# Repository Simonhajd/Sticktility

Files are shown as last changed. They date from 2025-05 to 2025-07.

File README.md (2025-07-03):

Stick-Tility (Stick Utility)

## About the Project / What it is:

Stick-Tility is a  handheld device that powers and reads data from snap-on sensor modules. Once a sensor is connected, it can record data at set time intervals and graph the data on its screen. It can charge via the USB-C on the side, and the KB2040 Microcontroller can be updated or connected to a computer using the same USB-C port. This all fits in a durable case smaller than a TV remote.

### Use cases:
* UV exposure logger
* * For example, you could easily set it up to record and display the current UV level and notify you when it reaches a certain threshold. Then you could just swap the UV sensor with a VOC sensor and it would instantly show you data about your air quality.
* Gps recorder for activities
* Analyzing trends in weather
* VOC warning system
* Distance measuring tool
* Noise level safety warning
  
## My process:
When I was thinking of a project to create for Highway, I started by constraining myself to one of these four categories: Tools, Displays, Devices, and Interfaces. I chose to make a tool because I wanted something I could actually use. I decided on making the most compact tool I could. I came up with a few more contraints (handheld, battery powered), and started developing the tool. 

### Why:

I want to be able to use sensors more easily without wiring or breadboards. Stick-Tility removes the bulky computer and battery aspect of each individual tool and sensor, so you can simply snap on the sensor (with pogo pins, like a MacBook charger), and you will receive data. This means, for each sensor you would like to use, you just need the sensor (with i2c), and you just plug it in using a pogo system. One battery for everything. I wanted to build this since I loved the concept of a hot-swappable sensor device for whatever you'd like, that fits in your hand, with a hot-swappable sensor end which snaps on using just magnets and pins. 

Screenshot 2025-07-03 at 8 59 43 AM

Screenshot 2025-06-21 at 3 33 17 PM

Screenshot 2025-06-21 at 3 33 07 PM

## Case design process:

I designed the case to be easily taken apart for debugging/removal while still sitting solidly together. I came up with the concept of two "skeleton" parts I can slide over the PCB and battery to keep them in place, and a shell which I can slide the electronics into. after many tens of hours of work on the case, I came up with a design that should be very robust, as small as possible, and easy to use. I also have magnets to attach the additional components, and to snap the skeletons into the shell.

Screenshot 2025-06-21 at 3 21 40 PM

I created an explosion video of the model too to visualize the parts required on the build:

https://github.com/user-attachments/assets/41e0f8f3-01ee-4bec-a7f7-713455e94a45

### Past projects: 
The only PCB work I’ve done before is a single-layer PCB macropad. https://github.com/Simonhajd/Macropad. Ive done some cad practice but no projects. This was mostly the first time ive really challenged myself with CAD. Other than these, I have only done software/online work.

### Why this is worth 10 points: 
This isnt just a data reading device, this is a dynamic tool which can be easily programmed to compile data and visualize it, or record data over time. the device is allowed to be placed anywhere, start a recording, and log data every x hours. This product has the ability to be a part of a much larger ecosystem of tools and sensors. The intricate build of this case allows anything to be modularly swapped, and nothing is glued. There are so many parts which fit so seamlessly together to become one rigid device. Just two screws are used, and everything is held together by other objects, or magnets. The PCB contains two off-the-shelf boards, and many other features to optimize reliability and quality. Such as decoupling capacitors, data line tuning, and much more. And finally, roughly 67 hours were spent on this project.

### Total Hours spent: 66 Hours 33 Minutes

### Total price: $158.44

## BOM:

| Qty | Part | P/N | Supplier | Price | Link | Shipping + Tariffs | Tax | Total |
|-----|---|-----|---|---|---|---|-----|---|
| 1 | Adafruit PowerBoost 1000 Charger - Rechargeable 5V Lipo USB Boost @ 1A - 1000C | N/A | Adafruit | 19.95 | [Link](https://www.adafruit.com/product/2465) | 1.72 | 2.167 | 23.837 |
| 1 | On-Off Power Button / Pushbutton Toggle Switch | 1683 | Adafruit | 1.95 | [Link](https://www.adafruit.com/product/1683?gQT=1) | 1.92 | 0.387 | 4.257 |
| 1 | Adafruit KB2040 | 5302 | Adafruit | 8.95 | [Link](https://www.adafruit.com/product/5302) | 1.92 | 1.087 | 0 (own) |
| 1 | 2A Waterproof Magnetic Pogo Pin Connector (Male/Female) | N/A | Aliexpress | 13.38 | [Link](https://www.aliexpress.us/item/3256808648425959.html) | 0 | 1.338 | 14.718 |
| 1 | Gravity: GNSS GPS BeiDou Positioning Module with RTC - I2C&UART | DFR1103 | DFRobot | 17.9 | [Link](https://www.dfrobot.com/product-2815.html) | 15 | 3.29 | 36.19 |
| 1 | 128x64 OLED - SSD1306 - I2C | WEA012864DWPP3N00003 | Digikey | 9.53 | [Link](https://www.digikey.com/en/products/detail/winstar-display/WEA012864DWPP3N00003/20533255) | 1.208 | 1.0738 | 11.8118 |
| 1 | Decoupling Capacitor | C0402C104K9RACTU | Digikey | 0.1 | [Link](https://www.digikey.com/en/products/detail/kemet/c0402c104k9ractu/1090777) | 1.208 | 0.1308 | 1.4388 |
| 2 | 5.1kΩ Resistors | RC0603FR-075K1L | Digikey | 0.1 | [Link](https://www.digikey.com/en/products/detail/yageo/RC0603FR-075K1L/727268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) | 1.208 | 0.1308 | 1.4388 |
| 11 | 1mΩ Resistors | TLR3AWDTE2L00F | Digikey | 1.53 | [Link](https://www.digikey.com/en/products/detail/koa-speer-electronics-inc/tlr3awdte2l00f/9845546) | 1.208 | 0.2738 | 3.0118 |
| 1 | USB-C Connector | UJ31-CH-G-SMT-TR-67 | Digikey | 3.52 | [Link](https://www.digikey.com/en/products/detail/same-sky-formerly-cui-devices/UJ31-CH-G-SMT-TR-67/12702600) | 1.208 | 0.4728 | 5.2008 |
| 100 | Screw x2 | 90128A187 | McMaster-Carr | 8.41 | [Link](https://www.mcmaster.com/catalog/131/3561/90128A187) | 3.61 | 1.202 | 0 (own) |
| 1 | 2.40mm M3 Hex Nut x2 | 90591A250 | McMaster-Carr | 2.81 | [Link](https://www.mcmaster.com/catalog/131/3648/90591A250) | 3.61 | 0.642 | 0 (own) |
| 8 | Magnets (Disc OD 0.197) | 5902K47 | McMaster-Carr | 1.09 | [Link](https://www.mcmaster.com/products/magnets/magnets-2~/shape~disc/od~0-197/) | 3.61 | 0.47 | 5.17 |
| 1 | Adafruit Lithium Ion Cylindrical Battery - 3.7V 2200mAh | 1781 | Adafruit | 9.95 | [Link](https://www.adafruit.com/product/1781) | 1.92 | 1.187 | 13.057 |
| 1 | Sparkfun Multi-Directional Switch 5 Position - D-Pad (SMD) | COM-26850 | Sparkfun | 0.95 | [Link](https://www.sparkfun.com/multi-directional-switch-5-position-d-pad-smd.html) | 2.825 | 0.3775 | 4.1525 |
| 1 | Flexible Qwiic Cable - 200mm | PRT-17258 | Sparkfun | 1.95 | [Link](https://www.sparkfun.com/flexible-qwiic-cable-200mm.html) | 2.825 | 0.4775 | 5.2525 |
| 1 | Qwiic Cable - 100mm (cut in half) | PRT-14427 | Sparkfun | 1.5 | [Link](https://www.sparkfun.com/qwiic-cable-100mm.html) | 2.825 | 0.4325 | 4.7575 |
| 1 | SparkFun Micro Temperature Sensor | STTS22H | Sparkfun | 8.53 | [Link](https://www.sparkfun.com/sparkfun-micro-temperature-sensor-stts22h-qwiic.html) | 2.825 | 1.1355 | 12.4905 |
| 1 | PCB | N/A | JLCPCB | 2.1 | PCB in repo | 8.5 | 1.06 | 11.66 |

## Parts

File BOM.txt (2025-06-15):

UJ31-CH-G-SMT-TR-67 USB-C

2x 5.1kΩ resistors  - RC0603FR-075K1L

2x 1mohm resistors

Adafruit PowerBoost 1000 Charger - Rechargeable 5V Lipo USB Boost @ 1A - 1000C

Sparkfun Lithium Ion Cylindrical Battery - 3.7v 2200mAh

Sparkfun Multi-Directional Switch 5 Position - D-Pad (SMD)

On-Off Power Button / Pushbutton Toggle Switch - Aadafruit Product ID: 1683

https://www.aliexpress.us/item/3256808648425959.html

adafruit kb2040

128x64 OLED - SSD1306 - I2C

SparkFun Qwiic Connect System - 10cm Jumper Wires

decoupling cap: C0402C104K9RACTU X 4

Weather - 

SparkFun Micro Temperature Sensor - STTS22H (Qwiic)

GNSS - 

MAX-F10S L1/L5 dual-band GNSS receiver for sub meter-level accuracy with SMA connector

u-blox Multi-band Active GNSS Antenna - L1, L5 (ANN-MB5)

SCREWS

NUTS

UPDATE CAPACITOR ON MAIN BUILD TO BE THE CORRECT PAD SPACING. I DID NOT CHECK THIS 

CHECK THAT THE PIN NUMBERS CORRELATE TO THE CORRECT PADS. DID NOT CHECK THIS

X2 95263A134_Alloy Steel Socket Head Screw 

2X 2.40mm mM3 Hex Nut

MAGNETS * 8 5.75x2mm

NOT USING: 

"Node" system:

BA1AAPC battery holder

RP2040
RFM95CW radio module
PCB.SMAFRA.HT jack
TLV73333PDBVR regulator
CC0402KRX5R5BB105 1uF decoupling capacitor
ANT-915-NUB-ccc 915 MHz LPWA Whip Antenna

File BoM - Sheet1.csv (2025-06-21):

Quantity | Part | P/N | Supplier | Price | Link | Shipping + Tariffs | Tax | Total
1 | Adafruit PowerBoost 1000 Charger - Rechargeable 5V Lipo USB Boost @ 1A - 1000C | N/A | Adafruit | 19.95 | https://www.adafruit.com/product/2465 | 1.72 | 2.167 | 23.837
1 | On-Off Power Button / Pushbutton Toggle Switch - Aadafruit Product ID: 1683 | 1683 | Adafruit | 1.95 | https://www.adafruit.com/product/1683?gQT=1 | 1.92 | 0.387 | 4.257
1 | adafruit kb2040 | 5302 | Adafruit | 8.95 | https://www.adafruit.com/product/5302 | 1.92 | 1.087 | 11.957
1 | 1/5Pair 2A Waterproof Magnetic Pogo Pin Connector 2 3 4 5 6 Positions Pogopin Male Female 2.54 MM Spring Loaded DC Power Socket |  | Aliexpress | 13.38 | https://www.aliexpress.us/item/3256808648425959.html | 0 | 1.338 | 14.718
1 | Gravity: GNSS GPS BeiDou Positioning Module with RTC - I2C&UART | DFR1103 | DFRobot | 25.9 | https://www.dfrobot.com/product-2815.html | 15 | 4.09 | 44.99
1 | 128x64 OLED - SSD1306 - I2C | 3190-DLC0096DNOG-W-10-ND | Digikey | 33.41 | https://www.digikey.com/en/products/detail/dlc-display-co-ltd/DLC0096DNOG-W-10/24764440 | 1.208 | 3.4618 | 38.0798
1 | Decoupling Capacitor | C0402C104K9RACTU | Digikey | 0.1 | https://www.digikey.com/en/products/detail/kemet/c0402c104k9ractu/1090777 | 1.208 | 0.1308 | 1.4388
2 | 5.1kΩ resistors | RC0603FR-075K1L | Digikey | 0.1 | https://www.digikey.com/en/products/detail/yageo/RC0603FR-075K1L/727268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 | 1.208 | 0.1308 | 1.4388
11 (same price) | 1mohm resistors | TLR3AWDTE2L00F | Digikey | 1.53 | https://www.digikey.com/en/products/detail/koa-speer-electronics-inc/tlr3awdte2l00f/9845546 | 1.208 | 0.2738 | 3.0118
1 | USB-C | UJ31-CH-G-SMT-TR-67 | Digikey | 3.52 | https://www.digikey.com/en/products/detail/same-sky-formerly-cui-devices/UJ31-CH-G-SMT-TR-67/12702600 | 1.208 | 0.4728 | 5.2008
100 | Screw - x 2 | 90128A187 | McMaster-Carr | 8.41 | https://www.mcmaster.com/catalog/131/3561/90128A187 | 3.61 | 1.202 | 13.222
1 | 2.40mm M3 Hex Nut x 2 | 90591A250 | McMaster-Carr | 2.81 | https://www.mcmaster.com/catalog/131/3648/90591A250 | 3.61 | 0.642 | 7.062
8 | MAGNETS - | 5902K47 | McMaster-Carr | 1.09 | https://www.mcmaster.com/products/magnets/magnets-2~/shape~disc/od~0-197/ | 3.61 | 0.47 | 5.17
1 | Adafruit Lithium Ion Cylindrical Battery - 3.7v 2200mAh | 1781 | Adafruit | 9.95 | https://www.adafruit.com/product/1781 | 1.92 | 1.187 | 13.057
1 | Sparkfun Multi-Directional Switch 5 Position - D-Pad (SMD) | COM-26850 | Sparkfun | 0.95 | https://www.sparkfun.com/multi-directional-switch-5-position-d-pad-smd.html | 2.825 | 0.3775 | 4.1525
1 | Flexible Qwiic Cable - 200mm | PRT-17258 | Sparkfun | 1.95 | https://www.sparkfun.com/flexible-qwiic-cable-200mm.html | 2.825 | 0.4775 | 5.2525
1 | Qwiic Cable - 100mm (going to cut in half) | PRT-14427 | Sparkfun | 1.5 | https://www.sparkfun.com/qwiic-cable-100mm.html | 2.825 | 0.4325 | 4.7575
1 | SparkFun Micro Temperature Sensor | STTS22H | Sparkfun | 8.53 | https://www.sparkfun.com/sparkfun-micro-temperature-sensor-stts22h-qwiic.html | 2.825 | 1.1355 | 12.4905
1 | PCB |  | JLCPCB | 2.1 | PCB in repo | 8.5 | 1.06 | 11.66
 |  |  |  |  |  |  | Total Price | 225.753

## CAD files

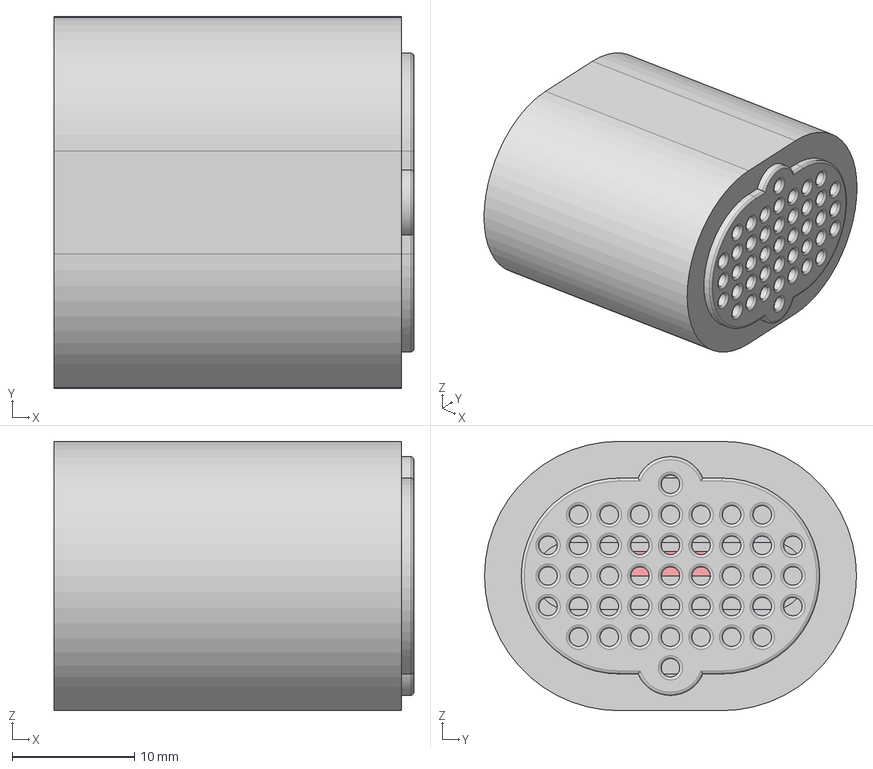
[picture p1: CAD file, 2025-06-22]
3D Models/Weathermodule.step
29.4 x 30.4 x 22.0 mm
Weathercase
WeatherSensor
WeatherMag
WeatherMag (1)

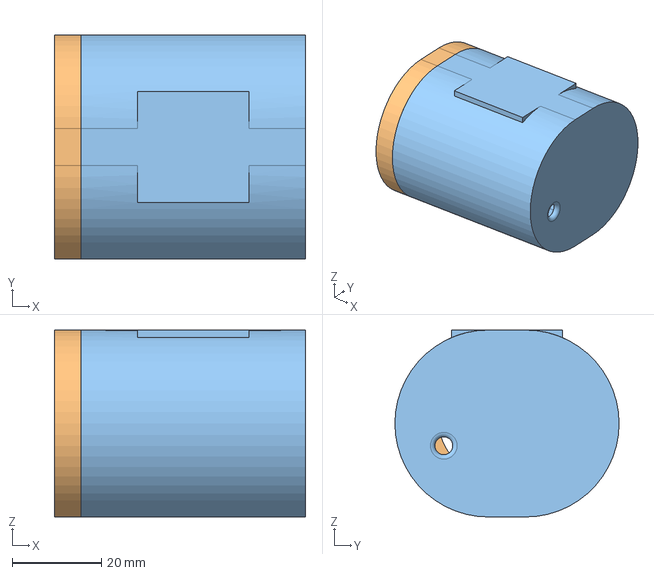
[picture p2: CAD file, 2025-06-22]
3D Models/GNSSBuild.step
56.4 x 50.4 x 42.0 mm

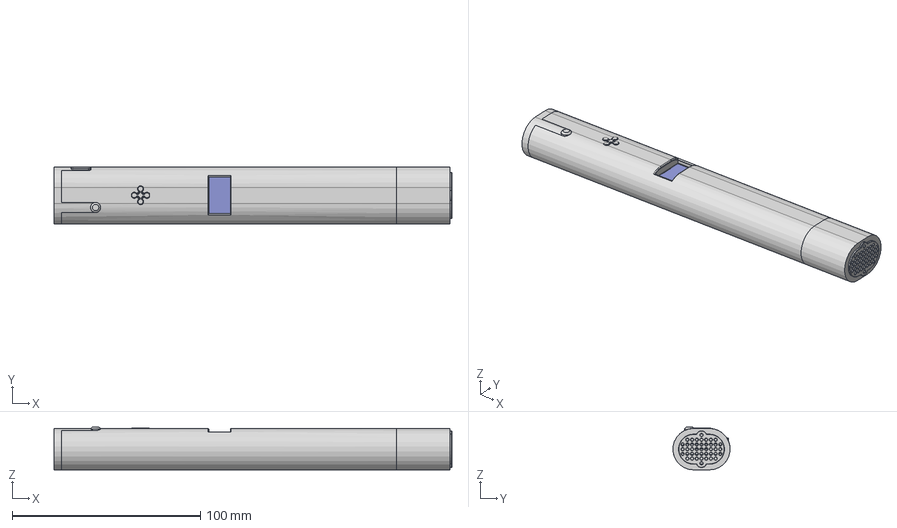
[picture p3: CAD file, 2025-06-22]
3D Models/Case v33.step
211.2 x 30.3 x 22.7 mm
Configuration 1
C_0201_0603Metric x 4
Navigation_SMD_9.9x9.9mm
R_0603_1608Metric x 4
board
screen
pin_header
soldering
smd_capacitor
smd_capacitor (1)
914_smd_resistor
472_smd_resistor x 3
t4_smd_diode
smd_capacitor (2)
smd_capacitor (3)
smd_capacitor (4)
smd_capacitor (5)
smd_capacitor (6)
472_smd_resistor (1)
SOT-23_XC6206 v3
smd_capacitor (7)
flat_cable
UJ31-CH-G-SMT-TR-67
powerboost 1000c.f3d v3_1
molex_0473460001
skibidishort 1.12.1
mightbeshit_PCB
90592A085_Steel Hex Nut x 2
90128A187_Zinc-Plated Alloy Steel Socket Head Screw x 2
Weatherbox
WeatherSensor
WeatherMag (1)
WeatherMag
Weathercase
Cap
SmallSupportPins
BottomCage
BigSupportPins (1)
SmallSupportPins (1)
ShellMagnets
Button
TopCage
Outside
ShellMagnets (1)

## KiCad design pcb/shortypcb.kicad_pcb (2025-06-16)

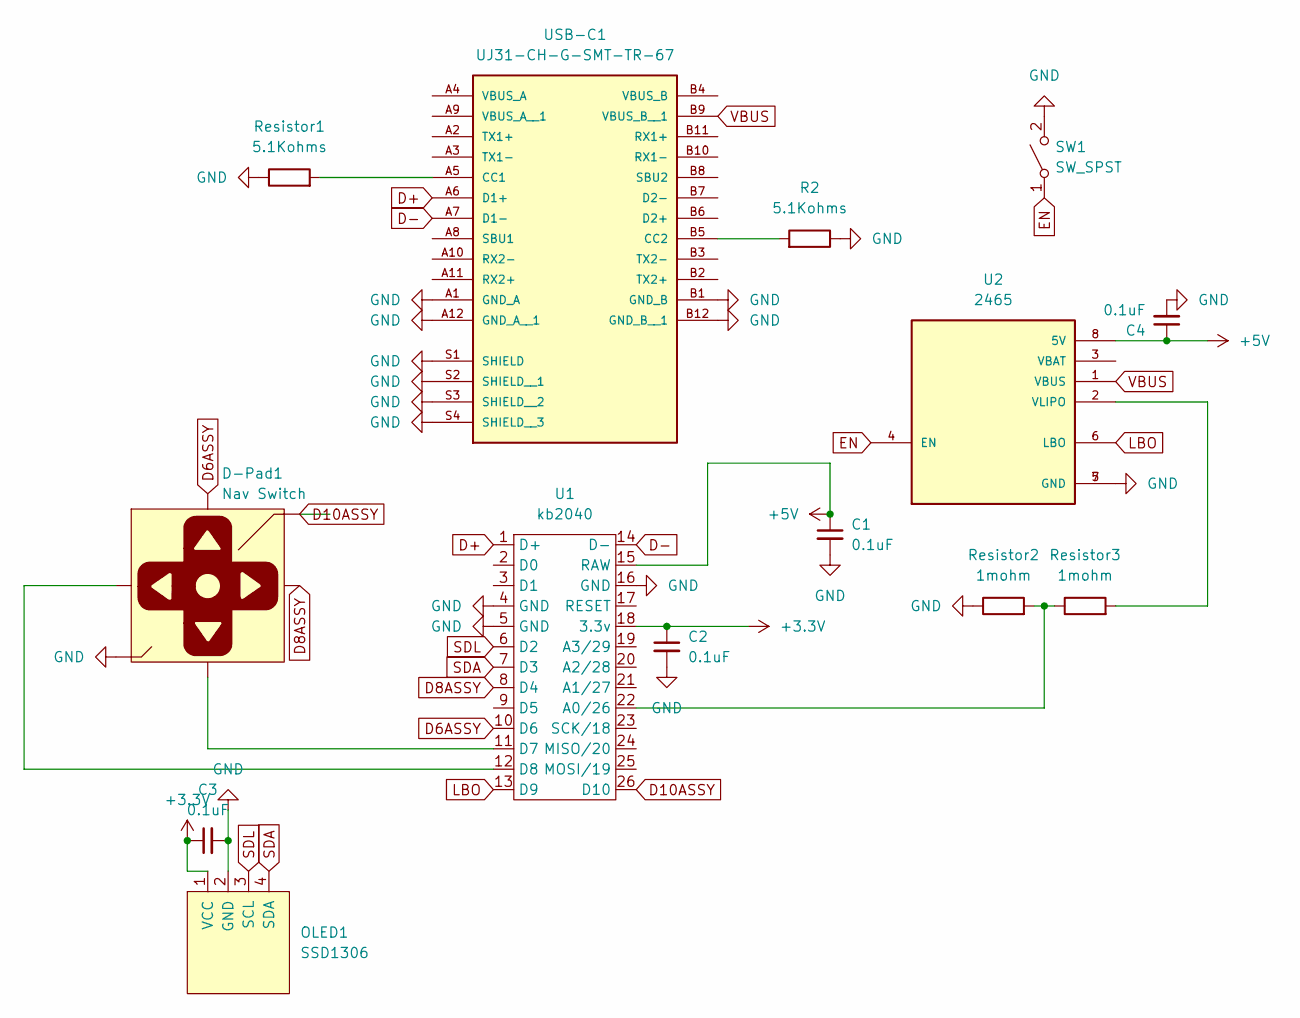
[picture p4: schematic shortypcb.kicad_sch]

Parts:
C1, C2, C3, C4: 0.1uF; CAPC1005X60
D-Pad1: Nav Switch; Navigation_SMD_9.9x9.9mm
OLED1: SSD1306; PinHeader_1x04_P2.00mm_Vertical
R2: 5.1Kohms; R_0603_1608Metric_Pad0.98x0.95mm_HandSolder
Resistor1: 5.1Kohms; RC0603N_YAG
Resistor2, Resistor3: 1mohm; RES_TLR_3AW1_2_4_KOA
SW1: SW_SPST; onoffswitch
U1: kb2040
U2: 2465; MODULE_2465; PARTREV B
USB-C1: UJ31-CH-G-SMT-TR-67; CUI_UJ31-CH-G-SMT-TR-67; PARTREV 1.0

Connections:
+3.3V: C2.1, C3.1, OLED1.1 (VCC), U1.18 (3.3v); also elsewhere on the board
+5V: C1.1, C4.1, U1.15 (RAW), U2.8 (5V)
D6ASSY: D-Pad1.1 (Up), U1.10 (D6)
D8ASSY: D-Pad1.2 (Right), U1.8 (D4)
D10ASSY: D-Pad1.4 (Center), U1.26 (D10)
D+: U1.1 (D+), USB-C1.A6 (D1+)
D-: U1.14 (D-), USB-C1.A7 (D1-)
EN: SW1.1 (A), U2.4 (EN)
GND: C1.2, C2.2, C3.2, C4.2, D-Pad1.3 (GND), D-Pad1.6 (GND), D-Pad1.8 (GND), D-Pad1.9 (GND), D-Pad1.10 (GND), OLED1.2 (GND), R2.1, Resistor1.1, Resistor2.1, SW1.2 (B), U1.4 (GND), U1.5 (GND), U1.16 (GND), U2.5 (GND), U2.7 (GND), USB-C1.A1 (GND_A), USB-C1.A12 (GND_A__1), USB-C1.B1 (GND_B), USB-C1.B12 (GND_B__1), USB-C1.S1 (SHIELD), USB-C1.S2 (SHIELD__1), USB-C1.S3 (SHIELD__2), USB-C1.S4 (SHIELD__3); also elsewhere on the board
LBO: U1.13 (D9), U2.6 (LBO)
unnamed: Resistor2.2, Resistor3.1, U1.22 (A0/26)
unnamed: D-Pad1.5 (Down), U1.11 (D7)
unnamed: D-Pad1.7 (Left), U1.12 (D8)
unnamed: Resistor3.2, U2.2 (VLIPO)
unnamed: Resistor1.2, USB-C1.A5 (CC1)
unnamed: R2.2, USB-C1.B5 (CC2)
SDA: OLED1.4 (SDA), U1.7 (D3); also elsewhere on the board
SDL: OLED1.3 (SCL), U1.6 (D2); also elsewhere on the board
VBUS: U2.1 (VBUS), USB-C1.B9 (VBUS_B__1)

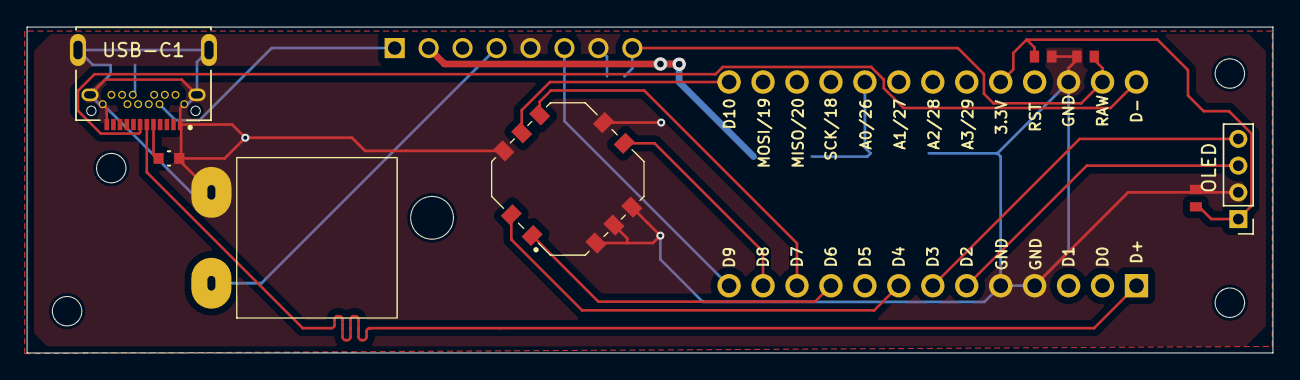
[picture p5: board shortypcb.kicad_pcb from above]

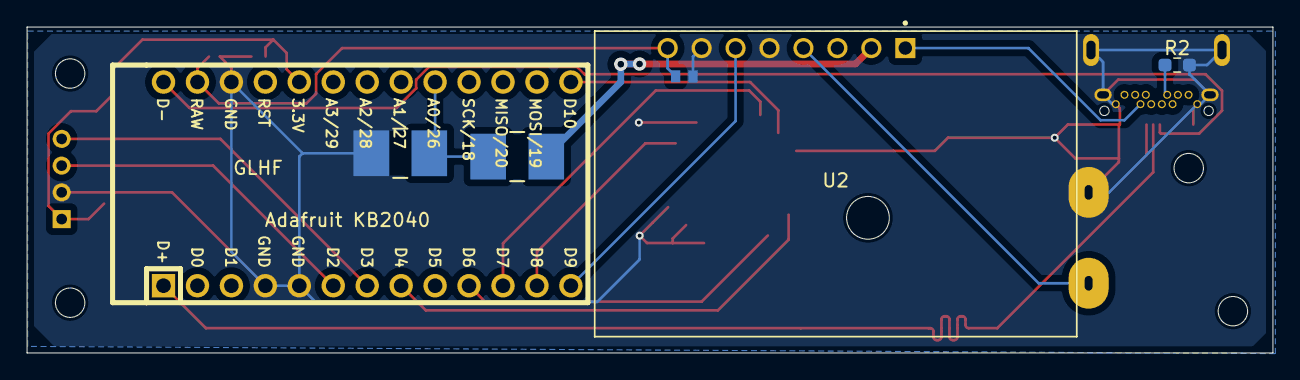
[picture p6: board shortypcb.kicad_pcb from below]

Board: 2 copper layers, 93.2 x 24.4 mm, 14 parts (6 on the bottom side), 19 nets.

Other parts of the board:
OLED: SSD1306; PinHeader_1x04_P2.00mm_Vertical

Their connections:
+3.3V: OLED.1 (VCC); also elsewhere on the board
GND: OLED.2 (GND); also elsewhere on the board
SDA: OLED.4 (SDA); also elsewhere on the board
SDL: OLED.3 (SCL); also elsewhere on the board

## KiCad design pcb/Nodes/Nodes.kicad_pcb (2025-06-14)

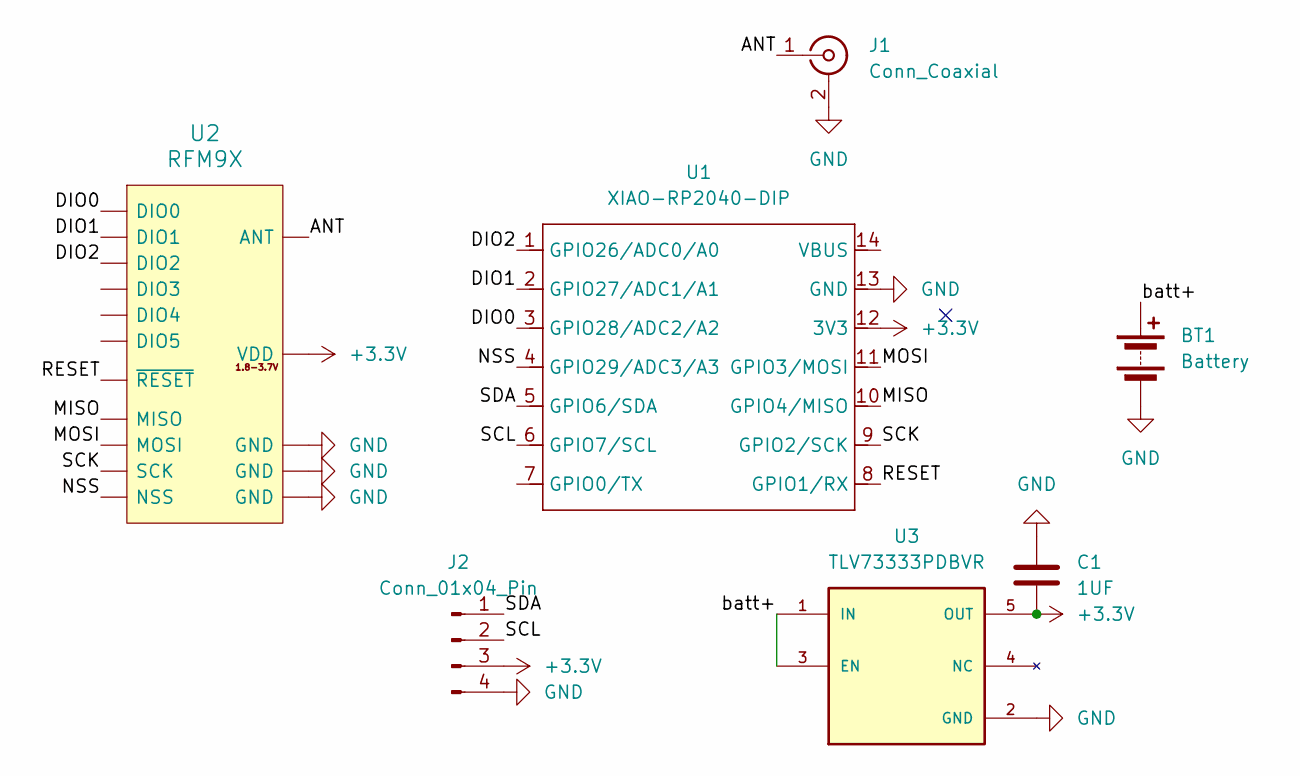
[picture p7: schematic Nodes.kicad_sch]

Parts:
BT1: Battery; BAT_BA1AAPC
C1: 1UF; CAPC1005X60
J1: Conn_Coaxial; CONN_PCB.SMAFRA_TAL
J2: Conn_01x04_Pin; pads
U1: XIAO-RP2040-DIP
U2: RFM9X; HOPERF_RFM9XW_SMD
U3: TLV73333PDBVR; SOT95P280X145-5N; PARTREV C

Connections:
+3.3V: C1.2, J2.3, U1.12 (3V3), U2.12 (VDD), U3.5 (OUT)
/ANT: J1.1 (In), U2.16 (ANT)
/DIO0: U1.3 (GPIO28/ADC2/A2), U2.11 (DIO0)
/DIO1: U1.2 (GPIO27/ADC1/A1), U2.10 (DIO1)
/DIO2: U1.1 (GPIO26/ADC0/A0), U2.9 (DIO2)
/MISO: U1.10 (GPIO4/MISO), U2.2 (MISO)
/MOSI: U1.11 (GPIO3/MOSI), U2.3 (MOSI)
/NSS: U1.4 (GPIO29/ADC3/A3), U2.5 (NSS)
/RESET: U1.8 (GPIO1/RX), U2.6 (~RESET)
/SCK: U1.9 (GPIO2/SCK), U2.4 (SCK)
/SCL: J2.2, U1.6 (GPIO7/SCL)
/SDA: J2.1, U1.5 (GPIO6/SDA)
/batt+: BT1.1 (+), U3.1 (IN), U3.3 (EN)
GND: BT1.2 (-), C1.1, J1.2 (Ext), J2.4, U1.13 (GND), U2.1 (GND), U2.8 (GND), U2.15 (GND), U3.2 (GND)

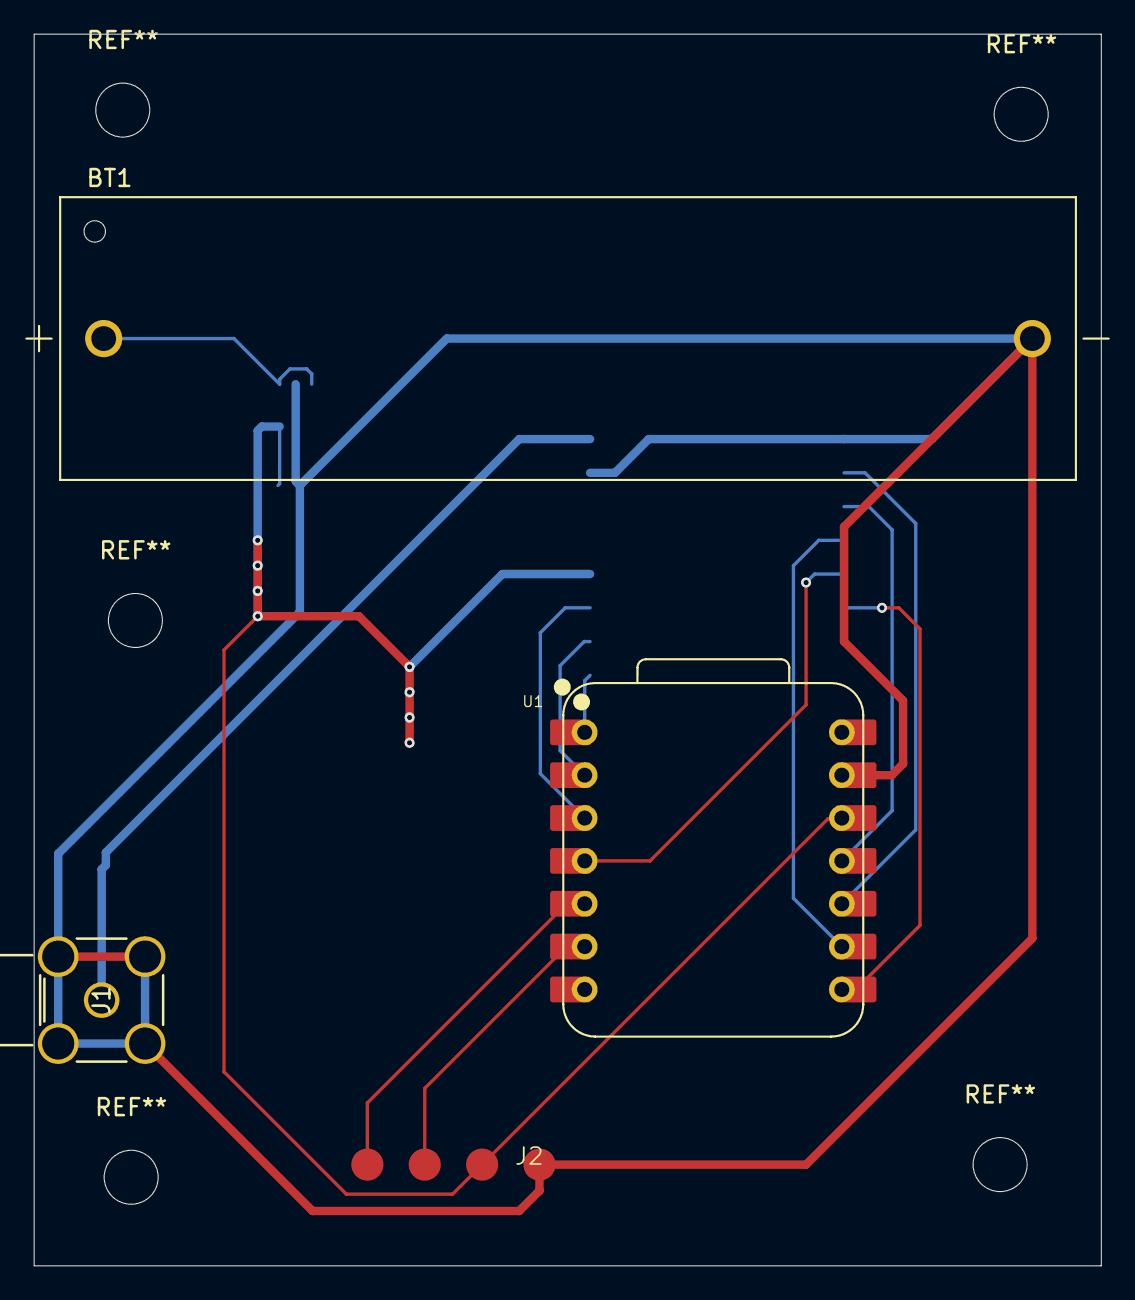
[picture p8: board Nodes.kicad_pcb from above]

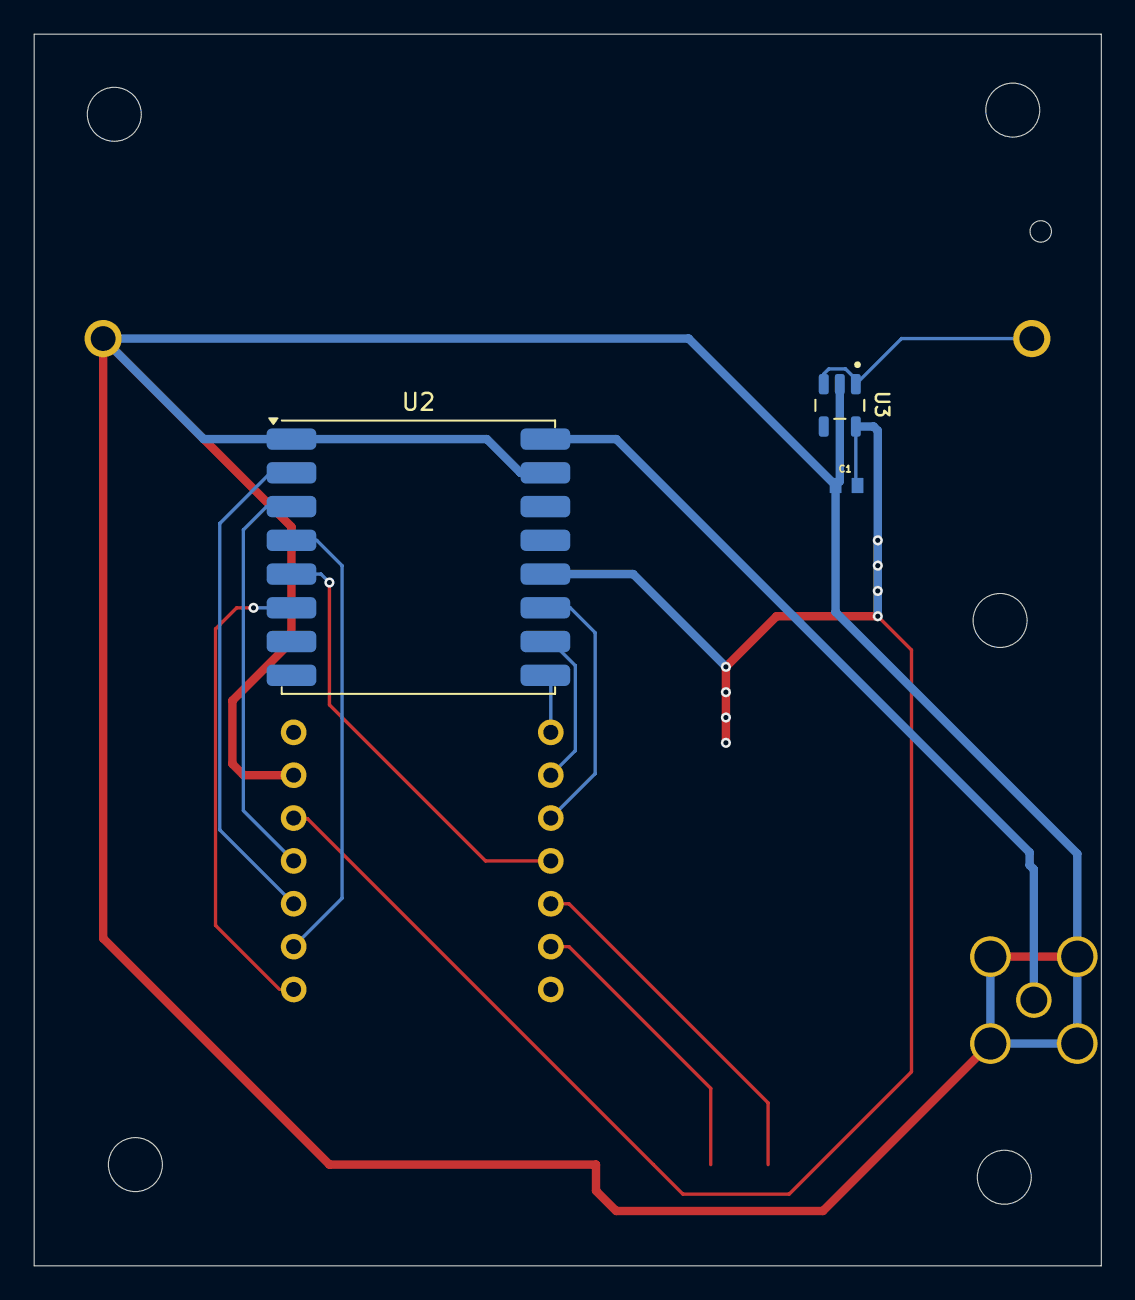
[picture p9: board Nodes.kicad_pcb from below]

Board: 2 copper layers, 63.2 x 73.0 mm, 7 parts (3 on the bottom side), 14 nets.

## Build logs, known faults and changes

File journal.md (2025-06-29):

---
title: "Sticktility"
author: "Simon"
description: "A stick with many utilities! (addons)"
created_at: "2024-05-26"
---

#Total Hours: 66 Hours 33 Minutes
 
#May 26: 
I started the concept - I realized the idea and brainstormed the concept of how it would generally come together. I listed what parts I should use, and what I would need. I figured out what capacitors I need, and what board to use. I settled on the adafruit kb2040 since I have a bunch of them laying around, a 128x64 oled for the screen, and I have figured out anything else yet. Im going to challenge myself with board constraints though, to ensure it stays like a stick - 0.91 inch wide (23mm). 

** Total time spent: 1 Hour **

#May 27: 

I decided I should start with pcb work, since everything else is essentially a shell. I found the kb2040 has an adafruit Qwiic connector, which means I could use that as the data transfer tool . not sure yet though. I also worked more on the concept - a rectangular tool, which has devices you can plug in to use. like a pocket sized multimeter, Ai quality sensor, solderer? and much more. you can also charge it with a winder tool, solar panel attachment, or whatever else. I also researched the last parts I should need - I found the d pad that works best is from sparkfun (in BOM), and the usb-c off of digikey (most waterproof one I could find). I also found the battery charger and battery from adafruit - the charger seems packed with features so I dont need to make them in my pcb. I also started on the pcb outline! made the concepts in the schematic editor.

Screenshot 2025-06-25 at 6 01 42 PM
Screenshot 2025-06-25 at 6 03 09 PM
Screenshot 2025-06-25 at 6 04 00 PM

** Total time spent: 3 Hours **

May 28:

Friend told me I need capacitors and resistors so had to do math to figure those out. I added those to the BOM and finished the schematic. I then started to outline the pcb and added the parts in. 80% of the way through, I realized the traces just wouldnt work unless I flipped the battery charger so had to restart. I also found a kicad-wakatime issue that meant it wasnt logging my hours :(

** Total time spent: 2 Hours **

#May 29: 

didnt do much - was busy. Just worked on tracing the new stuff. and found a lot of small inconsistencies in the footprint linking. had to redo most of them. I also added solder pads to the board instead of through hole pins for the on-off switch. (yet to find one that isnt tiny and annoying)

** Total time spent: 1 Hour **

#May 30: 

I tried to finish the PCB. I learned about Via's and I used that to complete the wiring I couldnt figure out at all. I asked chatgpt if I was missing anything and it suggested ground fills, so I had to reasearch how those work and how there helpful. I then tried to clear as many errors as possible, but still stuck on the solder mask problems around the tiny pins on the USB-C. other than that the PCB should be done now though! not gonna print until im sure im not going to make an expensive heater though. I also found I wasnt publishing the journal so just did that.

Screenshot 2025-05-30 at 6 08 56 PM
Screenshot 2025-05-30 at 6 08 46 PM

** Total time spent: 4 Hours **

#May 31: 

I worked a lot on finding the right screen to use, (TFT vs OLED, are the extra pins worth it?, what power do I need? should I use qwiic?), and I had to change my pcb around to accomodate the new oled. I then found 3d models for each model and used those to make a more accurate visualization of the board. Im now ready to work on the case finally!




** Total time spent: 4 hours 31 minutes **

#June 1:

Had to take time off for school but I went back to the pcb and had to make sure it size as effecient as possible. I figured out how to shink it by about 20-25% lengthwise so it is much smaller now. Took a while.

Screenshot 2025-06-25 at 5 03 59 PM
Screenshot 2025-06-25 at 5 03 55 PM

** Total time spent: 4 hours 24 minutes **

#june 2:

I worked on mounting the pcb to the shells. I delevoped a case concept where there are two peices that close on the pcb mounting holes(I also made today). this should make it secure and fit into the outer shell without any movevent. There cut so they slide in perfectly. havent figured out how to clip them into the outer shell yet though.

Screenshot 2025-06-25 at 5 11 18 PM

** Total time spent: 4 hours 21 minutes **

#June 3:

Updated the case design to match the new board and worked on the USB-C mechanism. (since its angled the cap cant just slide to go over it.) I made a cutout on the side, so the cap can encase it as it slides in. working on how to secure the cap now. Ive been working on different latching mechanisms but I want it to be able to come apart easily. I did research on different methods of latches using 3d printed parts but i dont think they would be reliable enough when made this small. I thought of using magnest but I feel like it needs to be secured on all axis, so it would be really strong magnets, and I also just dont have that space. I landed on M3 nuts and screws to hold it since it would properly keep the top and bottom of the cage together while being very low profile and compact.
Screenshot 2025-06-25 at 5 21 14 PM

** Total time spent: 4 hours 16 minutes **

June 5:

I spent a while today figuring out how the buttons can work through the case. I decided on having "extenders" reach down to press the buttons, and thin connectors to join them with the case. I added an extender on the inside, and on the outside shell. This took a lot longer than expected as my timeline was very messed up and when I went back to add them, I essentially had to redo the cap design. Ive also never used multiple sketches to make complex geometry (connecting the pads to the top, while ensuring the "sticks" were held on barely enough so they would click through the case), and I feel like I really nailed it with the design for the buttons. I also realized I needed supports for the OLED screen, so I used some profiles and extrusions to make small printable pieces to supoprt that, that seamlessly fit into the supports I made for the pcb board. (They all work together structurally now.) I also had to modify the 3d model of the OLED to match up eith the mounting holes, and i had to modify the case supports so not only will the support pins hold the oled, but the pins will make it become part of the shell. (Tall rods are put in the shell components to stablize the support pins )

Screenshot 2025-06-25 at 5 25 19 PM
Screenshot 2025-06-25 at 5 26 15 PM

** Total time spent: 5 hours 35 minutes **

June 6:

I figured the best way to go was just with M3 screws and nuts for the cap. I created slots to hold them and secure it together. the cap will join with the upper and lower cage (when there in place), then slide in. It looks really good too. 

Screenshot 2025-06-25 at 5 17 34 PM

I still need to work on:

on/off button
holding the cage to the case
pogo pin concept for the attachments
attachments

** Total time spent: 2 hours 16 minutes **

June 7:

I started on the pogo pin concept for easily attaching attachments. spent a while browsing and landed on one which has magnetics, and reverse polarity protection. I 3d modeled both sides of it and implemented it into the design, and moved over the battery to make space for its wires. turns out my timeline was messed up so the battery took a while to move, while maintaining its cutouts in the top and bottom "cage" (to secure it in place).

Screenshot 2025-06-13 at 10 54 44 PM

** Total time spent: 4 hours 23 minutes **

June 8: 

I started on the button design. turns out I think this project is going to be much smaller than I expected but thats not a problem. I looked into using the usb-c, or an attachment device, to be detected to turn it on, but figured I should have a hardwired button. I found a small enoguh latching button on adafruit im planning on using, I implemented it into the pcb, and I modeled it in Fusion. then added the same cutout style I did with the usb-c to let it slide in.

Screenshot 2025-06-13 at 10 53 23 PM

** Total time spent: 3 hours 53 minutes **

June 9: 

I started on the design to attach the cages to the outer shell. I landed on (hopefully) strong magnets since I really didnt want screws on both ends, or a flimsy 3d printed latch.

Screenshot 2025-06-25 at 6 12 17 PM

** Total time spent: 1 hours 12 minutes **

June 10: 

I started on the external device. I figured a simple sparkfun tempature sensor would be pretty compact and easy to start with. I modeled a cage for it and worked out how it would connect. The magnets on the pogo and on the case will help it stay attached. *Note I didnt include pictures of the inside since I think I can kinda stuff the sensor in there with some glue. Its boring I promise.
Screenshot 2025-06-13 at 10 49 43 PM
Screenshot 2025-06-13 at 10 49 56 PM

** Total time spent: 1 hours 38 minutes **

June 11:

I figured out how to get my fusion360 files onto github (way too late I know). I did that along with pushing my journal out

** Total time spent:  33 minutes **

June 12:

I first tried to make an "Explosion" animation of my finished device to put onto my readme/journal soon. I fixed my BOM to include all the parts on the build, and I started on some other modules. I researched GNSS vs GPS etc.. and I landed on including a GNSS module. I reached out to a gnss company and they gave me instructions on how to modify their IC's to tun in 3.3v which was pretty cool. Id rather go with a cheaper module though. Then I came up with another amazing idea of a "Node" - or a secondary device, that can send data to the main device over LoRa. I picked out the parts required for that, and did the schematic, and started on the pcb. I got good progress on the pcb too. called it project "Nodes"

https://github.com/user-attachments/assets/a90baea8-45bc-493b-a78d-f2a4c1781ec6

** Total time spent: 5 hours 12 minutes **

June 13:

I looked into the nodes more and built it out. I made the pcb, case, antenna setup, and everything for it. runs on 3.6v AA-like batteries. However I gotta abandon it. I cant send LoRa through Qwiic so thats gonna be my next project - lora radio. I worked on GNSS and made a module tho. I think im done with the builds for this project. in the end I got the base, the GNSS module, and the weather/temperature module. Im going to finalize the BOM, make the ReadMe, add the images if forgot to add, do the firmware ig? and publish.

Screenshot 2025-06-13 at 10 58 08 PM
Screenshot 2025-06-13 at 10 58 39 PM
Screenshot 2025-06-25 at 5 44 33 PM

** Total time spent: 5 hours 31 minutes**
 
June 14:

I updated the capacitors and resistors to really match real world items, so the pads will actually work, and I looked into tuning the length of wires for better signal so i did that. and i cleared up some DRC's. 53 more to go.

Trace tuning:
Screenshot 2025-06-25 at 6 06 39 PM

** Total time spent: 2 hours 12 minutes **

June 22:

Got some free time to hopefully finish this project. I cleared all the DRC's so I got 0 now. I finished the README and the .ino code to display the data on the kb2040. Ive never coded in arduino before so I learned about how pin variables worked and I downloaded the example code for how to use the oled, use the gnss module, and use the weather module, and basically combined them to all work together in one code. I also properly formatted my BOM in a google sheet and finalized it. I put all the files in here and submitted.

### Example workflow for the code:
Screenshot 2025-06-25 at 5 39 57 PM

### BOM building:

Screenshot 2025-06-25 at 5 41 04 PM

### Lack of DRC's 🙏:
Screenshot 2025-06-25 at 6 09 06 PM

** Total time spent: 4 hours 45 minutes **

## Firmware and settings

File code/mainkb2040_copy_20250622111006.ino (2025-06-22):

#include <Wire.h>
#include <Adafruit_GFX.h>
#include <Adafruit_SSD1306.h>
#include "SparkFun_STTS22H.h"
#include "DFRobot_GNSS.h"
#include "DFRobot_GNSSAndRTC.h"

#define SCREEN_WIDTH 128
#define SCREEN_HEIGHT 64
#define SCREEN_ADDRESS 0x3D
Adafruit_SSD1306 display(SCREEN_WIDTH, SCREEN_HEIGHT, &Wire, -1);
const int scl = 2;
const int sda = 3;

const int upPin = 6;
const int downPin = 7;
const int leftPin = 8;
const int rightPin = 4;
const int selectPin = 10;
const int lboPin = 9;







#define GNSS_ADDR 0x10
#define STTS22H_ADDR 0x3F 


SparkFun_STTS22H tempSensor;
DFRobot_GNSS_I2C gnss(&Wire, GNSS_ADDR);


bool hasGNSS = false;
bool hasTemp = false;

float tempF = 0.0;
float temp; 

void setup() {
  pinMode(upPin, INPUT_PULLUP);
  pinMode(downPin, INPUT_PULLUP);
  pinMode(leftPin, INPUT_PULLUP);
  pinMode(rightPin, INPUT_PULLUP);
  pinMode(selectPin, INPUT_PULLUP);
  pinMode(lboPin, INPUT);
  Wire.begin();

  Serial.begin(115200);
  if(!display.begin(SSD1306_SWITCHCAPVCC, SCREEN_ADDRESS)) {
    Serial.println(F("SSD1306 allocation failed"));
    for(;;); 
  }
  if( !tempSensor.begin() )
	{
		Serial.println("Temperature Sensor Did not Begin.");
		while(1);
	}
  
  if (gnss.begin()) {
    hasGNSS = true;
    gnss.enablePower();
    gnss.setGnss(gnss.eGPS_BeiDou_GLONASS);
  } else {
    Serial.println("GNSS not detected.");
  }

  
  tempSensor.setDataRate(STTS22H_POWER_DOWN);
	delay(10);
	tempSensor.setDataRate(STTS22H_1Hz);
  tempSensor.enableAutoIncrement();
  display.display();
  delay(2000);
  display.clearDisplay();
  

  

}

void loop() {
  
  if (hasGNSS) {
    DFRobot_GNSSAndRTC::sTim_t utc = gnss.getUTC();
	  DFRobot_GNSSAndRTC::sTim_t date = gnss.getDate();
	  DFRobot_GNSSAndRTC::sLonLat_t lat = gnss.getLat();
	  DFRobot_GNSSAndRTC::sLonLat_t lon = gnss.getLon();
	  double high = gnss.getAlt();
	  uint8_t starUserd = gnss.getNumSatUsed();
	  double sog = gnss.getSog();
	  double cog = gnss.getCog();
    display.println((char)lat.latDirection);
	  display.println((char)lon.lonDirection);
    display.print("alt high = ");
	  display.println(high);
    display.print("lat degree = ");
	  display.println(lat.latitudeDegree, 6);
	  display.print("lon degree = ");
	  display.println(lon.lonitudeDegree, 6);
  }
  if( tempSensor.dataReady() ) 
	{
    display.clearDisplay();
		tempSensor.getTemperatureF(&temp);

		display.print("Temp: "); 
		Serial.print(temp);
		display.println("F"); 
    display.display();

	} 
  if (analogRead(lboPin)) < 200 {
    display.clearDisplay();
    display.print("Battery Low!");
    display.display();
    delay(2);
  if (digitalRead(selectPin) == LOW) {
    display.clearDisplay();
    
    float batt = analogRead(lboPin) * (3.3 / 1023.0);
    Serial.print("Battery V: "); Serial.println(batt);
    
    display.println(analogRead(lboPin));
    display.display();
    delay(3000);
  }
  }
}

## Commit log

2025-05-28 PCB work
    pcb work - didnt commit the symbols and schematics since there not mine- dont wanna do something wrong
2025-05-29 Changed the filesystem+simplified. worked a lot on the pcb design.too
    [Adafruit KB2040.kicad_pcb, Adafruit KB2040.kicad_sch]
2025-05-29 gotta redo the board brahhh - the oled cant fit in the current orientation.
    [Adafruit KB2040.kicad_pcb]
2025-05-30 I messed around with the wiring more - now it should be done. need to do some final checks before sent off (whatever that means)
    [Adafruit KB2040.kicad_pcb, Adafruit KB2040.kicad_sch]
2025-05-31 Maybe finished the board? looks good to me. gonna look it over with others first
    [Adafruit KB2040.kicad_pcb, Adafruit KB2040.kicad_sch]
2025-05-31 Refreshed th eoled design to accomodate the screen i found - swapped vcc and gnd
    [Adafruit KB2040.kicad_pcb, Adafruit KB2040.kicad_sch]
2025-05-31 made the 3d model to pre for case design
2025-06-12 made the pcb a lot shorter- forgot to push
    [shortypcb.kicad_pcb, shortypcb.kicad_sch]
2025-06-13 addded the nodes concept. 7 hour day
    [Nodes.kicad_pcb, Nodes.kicad_sch]
2025-06-14 Node work + GNSS concept
    [Nodes.kicad_pcb, Nodes.kicad_sch, Reciever.kicad_pcb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]
2025-06-14 GNSS module build.
    [GNSSBuild v2.step]
2025-06-14 Node concept i probably wont use.
    [Nodes v5.step]
2025-06-15 uhh update june fourteeth
    [shortypcb.kicad_pcb, shortypcb.kicad_sch]
2025-06-16 PCB is done?
    [shortypcb.kicad_pcb]
2025-06-21 BOM BOM WOW WOW
    [BoM - Sheet1.csv]
2025-06-21 pcb updates - new resistors and slight layout work
2025-06-22 Moved the 3d models into its own folder
    [Case v33.step]
